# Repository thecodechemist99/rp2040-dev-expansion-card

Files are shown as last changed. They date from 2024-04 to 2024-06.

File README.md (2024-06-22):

# Dual RP2040 Expansian Card for Framework Laptop

This extension card includes two RP2040 microcontrollers and can be used as an internal
development board as well as external debugger for other RP2040-bsed boards (e.g. Raspberry
Pi Pico) or even entirely diffrent architectures.

## License

Expansion Card © 2024 by Florian Beck is licensed under CC BY 4.0.
Based on a reference design by Framework Computer Inc, licensed under CC BY 4.0, which can
be found [here](https://github.com/FrameworkComputer/ExpansionCards).
To view a copy of this license, visit http://creativecommons.org/licenses/by/4.0/

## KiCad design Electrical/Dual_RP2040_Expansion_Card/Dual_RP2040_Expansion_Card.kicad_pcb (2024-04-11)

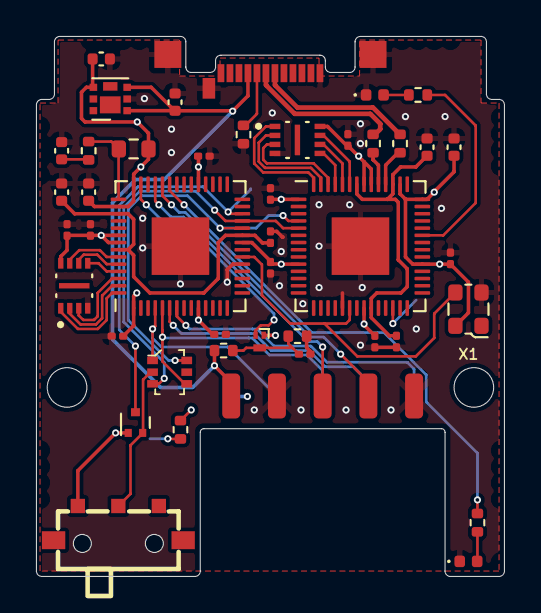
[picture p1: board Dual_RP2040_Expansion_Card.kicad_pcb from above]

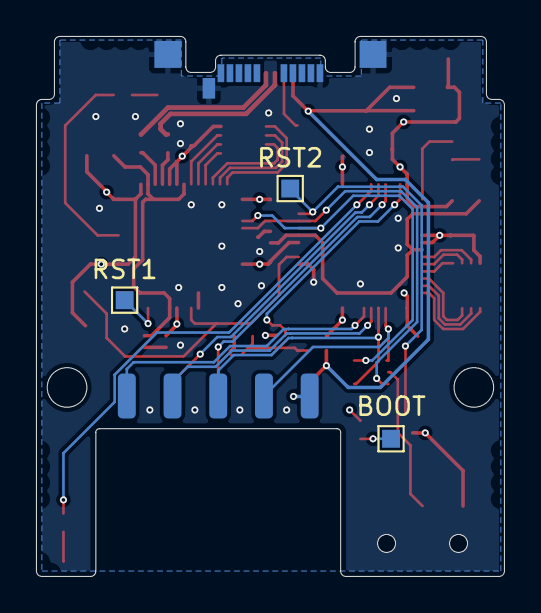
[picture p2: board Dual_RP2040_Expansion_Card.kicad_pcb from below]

Board: 4 copper layers, 26.0 x 30.0 mm, 53 parts (5 on the bottom side), 43 nets.

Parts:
C1, C2: 10u; C_0402_1005Metric
C5, C6, C10, C11, C12, C13, C16, C19, C20, C21, C22, C24: 100n; C_0201_0603Metric
C7, C8, C9, C14, C15: 2u2; C_0402_1005Metric
C18: 1n; C_0201_0603Metric
D1: Green; LED_0402_1005Metric
D2: Orange; LED_0402_1005Metric
H1, H2: MountingHole; MountingHole_2.2mm_M2
J1: Conn 10P; Pinheader_PCB_Edge_2x5_2.54mm
P1: USB_C_Plug_USB2.0; USB_C_Plug_Molex_105444
Q1: DMG1012T; Diodes_DFN1006-3
Q2: Q_PMOS_SGD; SOT-723
Q3: Q_Dual_NPN_NPN_C2E2C1E1B1B2; SOT-363
R1: 5k1; R_0402_1005Metric
R2: 1K; R_0402_1005Metric
R4, R17: 470R; R_0402_1005Metric
R9, R10: 27R; R_0402_1005Metric
R11: 200R; R_0603_1608Metric
R12: 1R; R_0402_1005Metric
R15: 200K; R_0402_1005Metric
R16: 100K; R_0402_1005Metric
S1: K3-1203S-E1; SW-SMD_K3-1203S-E1
TP1, TP2, TP3, TP4: TestPoint; TestPoint_Pad_1.5x1.5mm
TP5: BOOT; TestPoint_Pad_1.0x1.0mm
TP7: RST2; TestPoint_Pad_1.0x1.0mm
TP8: RST1; TestPoint_Pad_1.0x1.0mm
U1: AP7366EA-3.3; Diodes_UDFN2020-6_Type-F
U2, U4: RP2040; QFN-56-1EP_7x7mm_P0.4mm_EP3.2x3.2mm
U3, U5: W25Q16JVUXIQ; IC_W25Q16JVUXIQ_TR
X1: SX2M12.000M20F30TNN; Oscillator_SMD_ECS_2520MV-xxx-xx-4Pin_2.5x2.0mm

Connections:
+3V3: C2.1, C6.1, C8.1, C10.1, C11.1, C13.1, C15.1, C16.1, C19.1, C20.1, C21.1, C22.1, C24.1, J1.2, Q1.1 (G), Q2.1 (S), R2.2, R11.1, S1.1, U1.4 (VOUT), U2.1 (IOVDD), U2.10 (IOVDD), U2.22 (IOVDD), U2.33 (IOVDD), U2.42 (IOVDD), U2.44 (VREG_IN), U2.48 (USB_VDD), U2.49 (IOVDD), U3.8 (VCC), U4.1 (IOVDD), U4.10 (IOVDD), U4.22 (IOVDD), U4.33 (IOVDD), U4.42 (IOVDD), U4.44 (VREG_IN), U4.48 (USB_VDD), U4.49 (IOVDD), U5.8 (VCC), X1.4 (VDD)
/Debug Probe Section/1V1_CORE: C12.1, C14.1, U4.23 (DVDD), U4.45 (VREG_VOUT), U4.50 (DVDD)
/Debug Probe Section/LED_INT_EN: R17.1, U4.37 (GPIO25)
/Debug Probe Section/QSPI_SCLK: U4.52 (QSPI_SCLK), U5.6 (CLK)
/Debug Probe Section/QSPI_SD0: U4.53 (QSPI_SD0), U5.5 (DI/IO0)
/Debug Probe Section/QSPI_SD1: U4.55 (QSPI_SD1), U5.2 (DO/IO1)
/Debug Probe Section/QSPI_SD2: U4.54 (QSPI_SD2), U5.3 (~WP/IO2)
/Debug Probe Section/QSPI_SD3: U4.51 (QSPI_SD3), U5.7 (~HOLD/~RESET/IO3)
/Debug Probe Section/QSPI_SS: U4.56 (QSPI_SS), U5.1 (~CS)
/Development Board Section/1V1_CORE: C5.1, C7.1, U2.23 (DVDD), U2.45 (VREG_VOUT), U2.50 (DVDD)
/Development Board Section/ADC_VREF: R11.2, R12.1, U2.43 (ADC_AVDD)
/Development Board Section/GPIO_ADC3: Q1.2 (S), U2.41 (GPIO29_ADC3)
/Development Board Section/QSPI_SCLK: U2.52 (QSPI_SCLK), U3.6 (CLK)
/Development Board Section/QSPI_SD0: U2.53 (QSPI_SD0), U3.5 (DI/IO0)
/Development Board Section/QSPI_SD1: U2.55 (QSPI_SD1), U3.2 (DO/IO1)
/Development Board Section/QSPI_SD2: U2.54 (QSPI_SD2), U3.3 (~WP/IO2)
/Development Board Section/QSPI_SD3: U2.51 (QSPI_SD3), U3.7 (~HOLD/~RESET/IO3)
/Development Board Section/QSPI_SS: U2.56 (QSPI_SS), U3.1 (~CS)
/Development Board Section/RUN: Q2.3 (D), TP7.1, U2.26 (RUN)
DEV_ENABLE: Q2.2 (G), Q3.2 (B1), Q3.5 (B2), S1.2
GND: C1.2, C2.2, C5.2, C6.2, C7.2, C8.2, C9.2, C10.2, C11.2, C12.2, C13.2, C14.2, C15.2, C16.2, C18.2, C19.2, C20.2, C21.2, C22.2, C24.2, D1.1 (K), D2.1 (K), J1.3, J1.9, P1.A1 (GND), P1.A12 (GND), P1.B1 (GND), P1.B12 (GND), P1.S1 (SHIELD), R1.2, R16.2, TP1.1, TP2.1, TP3.1, TP4.1, U1.2 (GND), U2.19 (TESTEN), U2.57 (GND), U3.4 (GND), U4.19 (TESTEN), U4.57 (GND), U5.4 (GND), X1.2 (GND)
GPIO2: J1.4, Q3.1 (E1), U2.4 (GPIO2)
GPIO3: J1.6, Q3.4 (E2), U2.5 (GPIO3)
GPIO4: J1.8, U2.6 (GPIO4)
GPIO5: J1.10, U2.7 (GPIO5)
GPIO_ADC0: J1.7, U2.38 (GPIO26_ADC0)
GPIO_ADC1: J1.5, U2.39 (GPIO27_ADC1)
LED_EN: R4.1, U2.37 (GPIO25)
unnamed: C9.1, R12.2
unnamed: D1.2 (A), R4.2
unnamed: D2.2 (A), R17.2
unnamed: P1.A5 (CC), R1.1
unnamed: C18.1, Q1.3 (D), R15.2, R16.1
unnamed: R2.1, TP5.1
unnamed: TP8.1, U4.26 (RUN)
unnamed: R10.2, U4.46 (USB_DM)
unnamed: R9.2, U4.47 (USB_DP)
OSC_OUT: U2.20 (XIN), U4.20 (XIN), X1.3 (OUT)
SWCLK: Q3.6 (C1), U2.24 (SWCLK), U4.4 (GPIO2)
SWDIO: Q3.3 (C2), U2.25 (SWD), U4.5 (GPIO3)
USB_D_N: P1.A7 (D-), R10.1
USB_D_P: P1.A6 (D+), R9.1
VBUS: C1.1, J1.1, P1.A4 (VBUS), P1.A9 (VBUS), P1.B4 (VBUS), P1.B9 (VBUS), R15.1, U1.1 (EN), U1.3 (VIN)

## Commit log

2024-04-02 First rough draft
    [Expansion_Card_Retrofit.kicad_pcb, Expansion_Card_Retrofit.kicad_sch, debug_probe_section.kicad_sch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]
2024-04-02 Main layout of chip sections finished
    [Expansion_Card_Retrofit-CuBottom.gbr, Expansion_Card_Retrofit-CuIn1.gbr, Expansion_Card_Retrofit-CuIn2.gbr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]
2024-04-03 Current state before flash footprint update
    [Expansion_Card_Retrofit.kicad_pcb, Expansion_Card_Retrofit.kicad_sch, debug_probe_section.kicad_sch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]
2024-04-03 First complete version
    [Expansion_Card_Retrofit.kicad_pcb, Expansion_Card_Retrofit.kicad_sch, dev_board_section.kicad_sch]
2024-04-04 Current state
2024-04-09 All footprints placed single-sided
    [Expansion_Card_Retrofit.kicad_pcb, Expansion_Card_Retrofit.kicad_sch, debug_probe_section.kicad_sch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]
2024-04-09 Single layer basic layout finished
    [Expansion_Card_Retrofit.kicad_pcb, Expansion_Card_Retrofit.kicad_sch, debug_probe_section.kicad_sch]
2024-04-09 Added edge pin connector
    [Expansion_Card_Retrofit.kicad_pcb]
2024-04-10 Layout finished
    [Expansion_Card_Retrofit.kicad_pcb, Expansion_Card_Retrofit.kicad_sch]
2024-04-10 Added test points
    [Expansion_Card_Retrofit.kicad_pcb, debug_probe_section.kicad_sch, dev_board_section.kicad_sch]
2024-04-10 Production design v1 finished
    [Expansion_Card_Retrofit-CuBottom.gbr, Expansion_Card_Retrofit-CuIn1.gbr, Expansion_Card_Retrofit-CuIn2.gbr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]
2024-04-11 Fixed missing drill holes for switch
    [Expansion_Card_Retrofit-CuBottom.gbr, Expansion_Card_Retrofit-CuIn1.gbr, Expansion_Card_Retrofit-CuIn2.gbr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]
2024-06-22 Removed obsolete files
    [Expansion_Card.kicad_pcb, Expansion_Card.sch, Microcontroller.kicad_pcb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]
2024-06-22 Renamed files
    [Dual_RP2040_Expansion_Card-CuBottom.gbr, Dual_RP2040_Expansion_Card-CuIn1.gbr, Dual_RP2040_Expansion_Card-CuIn2.gbr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]

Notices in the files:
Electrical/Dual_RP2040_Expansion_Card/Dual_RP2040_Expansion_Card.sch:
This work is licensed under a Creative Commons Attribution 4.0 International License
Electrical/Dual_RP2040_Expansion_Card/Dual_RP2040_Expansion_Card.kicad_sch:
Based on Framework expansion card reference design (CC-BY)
